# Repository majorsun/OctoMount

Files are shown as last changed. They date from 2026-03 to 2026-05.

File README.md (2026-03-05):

# OctoMount

A 3D-printable mounting enclosure that attaches a **Raspberry Pi 4B** with **MPI4008 4" LCD touchscreen** to an **Ender 3 Pro** 3D printer frame.

Designed for use with [OctoPrint](https://octoprint.org/) — giving you a compact, integrated control panel mounted directly on your printer.

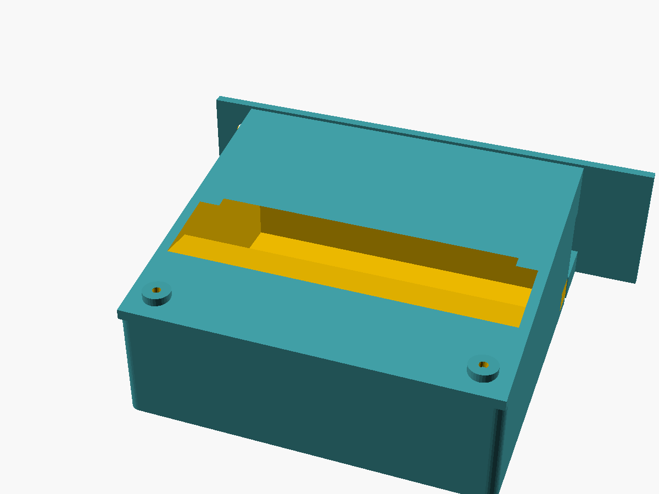
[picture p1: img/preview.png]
CAD Preview


> Preview auto-generated from `cad/assembly.scad` via `scripts/render_preview.sh`.
> Re-run the script after any CAD change to keep this image current.

---

## Hardware

| Component | Model | Notes |
|---|---|---|
| Single Board Computer | Raspberry Pi 4B | 2GB/4GB/8GB variants |
| Display | MPI4008 (LCDwiki 4" HDMI Display-C) | 800×480 IPS, resistive touch |
| Printer | Creality Ender 3 Pro | 4040 aluminum extrusion frame |

### MPI4008 Display Specs

- **Size:** 4.0 inch IPS
- **Resolution:** 800 × 480
- **Touch:** 4-wire resistive
- **Interface:** HDMI (video) + 13×2 GPIO header (power + touch)
- **Module dimensions:** 143 × 134 × 51 mm (with RPi stacked)

### Raspberry Pi 4B Specs

- **Dimensions:** 85 × 56 × 17 mm
- **Ports used:** HDMI micro (to LCD), USB-A (printer connection), USB-C (power in)

---

## Design Overview

OctoMount is a **2-piece design** — Base and Cover — that replaces the Ender 3 Pro control box front panel:

- **Base** — single printed part that serves as both the mounting bracket and the enclosure body. It bolts to the 4040 control-box beam using the existing two M5 diagonal screw holes, covers the stock front panel, and houses the RPi 4B, LM2596 buck converter, and full-size SD slot.
- **Cover** — angled lid that screws onto the Base. The back wall is at the full 48 mm height limit; the front wall is as short as the flat RPi stack allows, maximising the LCD tilt toward the operator. Attaches with 4× M3 screws.

### Mounting Strategy

The Base plate bolts directly to the end face of the Ender 3 Pro 4040 control-box beam using **2× M5 flat-head screws** in the existing diagonal hole pattern (top-left at 10,10 mm; bottom-right at 30,30 mm). Longer M5 screws pass through the Base plate and original plastic panel into the beam — no new holes required.

### Port Routing

| Port | Location | Purpose |
|---|---|---|
| Full-size SD slot | Left wall of Base | Ender 3 Pro microSD extension (print file access) |
| USB-A | Back wall of Base | Cable to Ender 3 Pro mainboard USB (routed through control box) |
| USB-C power | Right-bottom corner of Base | 5V from LM2596 buck converter, entering via 4040 T-slot channel |
| Micro HDMI | Internal | RPi → MPI4008 LCD (inside enclosure) |

---

## Project Goals

- [x] Design a 2-piece 3D-printable enclosure for RPi 4B + MPI4008 LCD + LM2596 buck converter
- [x] Mount to the Ender 3 Pro 4040 beam end face via existing M5 screw holes
- [ ] Power from Ender 3 Pro 24V PSU via LM2596 buck converter (→ 5V USB-C for RPi)
- [ ] Expose full-size SD slot on left wall (extended from Ender 3 Pro microSD)
- [ ] Route USB-A cable from Ender 3 Pro mainboard through back wall to RPi
- [ ] LCD tilt maximised toward operator (back wall at 48 mm, front wall at minimum height above flat RPi stack)
- [ ] Integrated fan ventilation with permanent dust filter mesh

---

## Deliverables

| File | Description | Status |
|---|---|---|
| `PARTS.md` | Full bill of materials — parts to buy + 3D printed parts list | ✅ Updated |
| `REQUIREMENTS.md` | Full design requirements | ✅ Updated |
| `stl/` | 3D print files (2 parts: Base + Cover) | 🔄 Pending CAD redesign |
| `docs/ASSEMBLY.md` | Enclosure diagram + step-by-step assembly instructions | 🔄 Pending |
| `img/wiring_diagram.png` | Wiring diagram (PSU → buck converter → RPi) | 🔄 Pending |
| `img/preview.png` | Auto-rendered CAD preview (regenerated by `scripts/render_preview.sh`) | ✅ Active |
| `img/renders/` | Final high-quality CAD renders | 🔄 Pending CAD |

---

## 3D Printed Parts

| Part | Description |
|---|---|
| Base | Mounting plate + arm shelf + enclosure walls + RPi bosses + SD slot + buck converter mount |
| Cover | Angled lid (45° front-top face) with LCD window cutout; attaches with 4× M3 screws |

---

## Repository Structure

```
OctoMount/
├── README.md
├── REQUIREMENTS.md        # Full design requirements
├── STATUS.md              # Project phase tracker
├── PARTS.md               # Bill of materials
├── cad/                   # OpenSCAD source files
├── stl/                   # Export-ready STL files for printing
│   ├── Base.stl
│   └── Cover.stl
├── docs/
│   └── ASSEMBLY.md        # Assembly instructions
├── scripts/
│   └── render_preview.sh  # Regenerate img/preview.png from CAD
└── img/                   # Renders, wiring diagram, photos
    └── preview.png        # Auto-rendered CAD preview
```

---

## Software

- [OctoPrint](https://octoprint.org/) — web-based 3D printer control
- [OctoPi](https://github.com/guysoft/OctoPi) — Raspberry Pi OS image with OctoPrint pre-installed
- [LCD driver (goodtft)](https://github.com/goodtft/LCD-show) — MPI4008 display driver (`sudo ./MPI4008-show`)

---

## Printing Notes

- Material: PETG recommended (heat resistance near printer)
- Layer height: 0.2 mm
- Infill: 30%+
- Supports: Minimal (design oriented to minimise overhangs)

---

## License

[MIT](LICENSE) — free to use, modify, and share.

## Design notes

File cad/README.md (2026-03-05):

# OctoMount — CAD Files

All source models are written in **OpenSCAD** (parametric, text-based CAD).

## Install OpenSCAD

Download the latest stable release from <https://openscad.org/downloads.html>
(Windows / macOS / Linux — free, open source)

## File overview

| File | Description | Render to get… |
|---|---|---|
| `params.scad` | All dimensions + derived values + shared modules | *(not a standalone part)* |
| `assembly.scad` | All parts positioned together | Full assembly preview |
| `p1_enclosure.scad` | Main body shell | `OctoMount_enclosure.stl` |
| `p2_bracket.scad` | 2020 extrusion clamp + tilted arm | `OctoMount_bracket.stl` |
| `p3_bezel.scad` | LCD front bezel + stylus clip | `OctoMount_bezel.stl` |
| `p4_rear_panel.scad` | Rear panel with hex vent cutouts | `OctoMount_rear_panel.stl` |
| `p5_buck_tray.scad` | Buck converter retention tray | `OctoMount_buck_tray.stl` |

## How to render a part

1. Open the `.scad` file in OpenSCAD
2. Press **F5** for a fast preview, or **F6** for a full render
3. Check the **Console** tab at the bottom — no errors means the geometry is valid
4. Export: **File → Export → Export as STL…** → save to `../stl/`

## How to render the assembly

1. Open `assembly.scad`
2. Press **F5** (preview) — colour-coded parts help distinguish components
3. Set `EXPLODE = 1;` at the top of the file for an exploded view, then press F5 again

## Iterating on dimensions

All dimensions live in **`params.scad`**.
- Items marked `// TBD` must be confirmed against the physical hardware before printing
- Edit the relevant parameter value, save, and press F5 in OpenSCAD to see the change
- No other files need changing for pure dimension tweaks

## Which file to open for each change

| Change type | File to edit |
|---|---|
| Hardware dimensions, clearances | `params.scad` |
| New openings, port positions, cavity shape | `p1_enclosure.scad` |
| Bracket tilt angle, clamp depth, arm length | `p2_bracket.scad` |
| Bezel border width, stylus clip profile | `p3_bezel.scad` |
| Vent pattern size/density, voltmeter window | `p4_rear_panel.scad` |
| Buck tray inner dimensions, wire holes | `p5_buck_tray.scad` |

## Print settings (recommended)

- Material: **PETG** (heat resistant near printer, good layer adhesion)
- Layer height: 0.2 mm
- Walls: 3 perimeters
- Infill: 30 % gyroid
- Supports: only on bracket arm overhang if TILT > 45°

## TBD items (measure before final print)

See `params.scad` — every line marked `// TBD` needs physical measurement:

- LCD PCB outer dimensions (`LCD_PCB_X`, `LCD_PCB_Z`, `LCD_T`)
- RPi 4B total thickness with heatsinks (`RPI_T`)
- Fan size and thickness (`FAN_SIZE`, `FAN_T`)
- Buck converter PCB dimensions (`BUCK_L`, `BUCK_H`, `BUCK_W`)
- All port centre positions on RPi (`RPI_ETH_Z`, `RPI_USBC_Z`, etc.)
- Stylus diameter (`STYLUS_D`)
- SD extension slot opening size (`SD_SLOT_W`, `SD_SLOT_H`)

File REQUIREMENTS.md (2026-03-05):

# Design Requirements

**Last Updated:** 2026-03-04 (rev 2)
**Design:** 2-piece enclosure (Base + Cover) — see STATUS.md for design pivot history

---

## REQ-001 — Hardware Compatibility

| ID | Requirement | Priority |
|---|---|---|
| REQ-001.1 | Base must house Raspberry Pi 4B (85 × 56 × 17 mm) with clearance | MUST |
| REQ-001.2 | Cover must provide an angled LCD window for the MPI4008 display (active area ~87 × 52 mm) | MUST |
| REQ-001.3 | Base must bolt to the Ender 3 Pro 4040 control-box beam end face via 2× M5 flat-head screws | MUST |
| REQ-001.4 | USB-C power port on RPi must receive 5V from the internal LM2596 buck converter via a USB-C pigtail routed through the right-bottom corner | MUST |
| REQ-001.5 | A USB-A cable must exit through the back wall of the base to connect the RPi to the Ender 3 Pro mainboard USB port (routed internally through the control box) | MUST |
| REQ-001.6 | RPi microSD slot is not required to be accessible from outside (OctoPi OS is pre-flashed) | INFO |
| REQ-001.7 | Micro HDMI port on RPi must be routed to the LCD internally | MUST |
| REQ-001.8 | MPI4008 GPIO 13×2 header connection to RPi must be accommodated | MUST |
| REQ-001.9 | Enclosure must include a full-size SD card slot on the left wall, connected via microSD male → SD female extension cable (AliExpress item 2255801037535913) to the Ender 3 Pro control box microSD slot | MUST |
| REQ-001.10 | SD extension cable must reach from the Ender 3 Pro mainboard to the left-wall SD slot without tension — verify cable length before ordering | MUST |
| REQ-001.11 | MPI4008 backlight button access is optional | NICE-TO-HAVE |
| REQ-001.12 | MPI4008 3.5mm audio jack access is not required | OUT-OF-SCOPE |

---

## REQ-002 — Structural & Mounting

| ID | Requirement | Priority |
|---|---|---|
| REQ-002.1 | Base plate must bolt to the Ender 3 Pro 4040 control-box front beam end face using 2× M5 flat-head screws in the existing diagonal hole pattern (10,10) and (30,30) — 20 mm apart in X and Z | MUST |
| REQ-002.2 | The base plate covers the stock Ender 3 Pro control box front panel entirely | MUST |
| REQ-002.3 | Assembly must withstand vibration during printing without loosening | MUST |
| REQ-002.4 | No 2020 T-slot nuts or 2020 clamp hardware required | MUST |
| REQ-002.5 | Total enclosure height (Z, including all walls) must not exceed **48 mm** — hard clearance limit from the Ender 3 Pro bed assembly | MUST |
| REQ-002.6 | RPi 4B must be mounted flat (85 × 56 mm footprint in XY, PCB+heatsinks ~17–25 mm in Z) — standing on-edge is ruled out by the 48 mm height limit | MUST |
| REQ-002.7 | LCD tilt must be **maximised toward the operator**: back wall at the full 48 mm, front wall at the minimum height dictated by the flat RPi stack + clearance. Do not target a fixed angle — derive it from the geometry | MUST |
| REQ-002.8 | Side silhouette: right-trapezoid — back wall tall (48 mm), front wall short (minimum), angled top face spanning between them holding the LCD | MUST |
| REQ-002.9 | Assembly must support the combined weight of RPi 4B + LCD without flex | MUST |
| REQ-002.10 | Assembly must not protrude into the path of the printer bed (Y-axis travel) | MUST |
| REQ-002.11 | Assembly must not obstruct the X-axis gantry wheels or carriage movement | MUST |
| REQ-002.12 | Full-size SD card slot must be on the left wall and allow one-handed card insertion/removal | MUST |
| REQ-002.13 | Cover must attach to Base with M3 screws (no glue) and be removable for service | MUST |

---

## REQ-003 — Power

| ID | Requirement | Priority |
|---|---|---|
| REQ-003.1 | Assembly must draw power from the Ender 3 Pro PSU (24V DC) — no separate wall adapter | MUST |
| REQ-003.2 | Buck converter model: LM2596-based adjustable step-down (Temu goods_id 601099525293943) | MUST |
| REQ-003.3 | Buck converter must be set to output 5V DC for RPi 4B | MUST |
| REQ-003.4 | Buck converter output must supply at least 3A continuous | MUST |
| REQ-003.5 | Buck converter must be mounted inside the base body with adhesive thermal pad/heatsink (~14 × 14 mm aluminum) | MUST |
| REQ-003.6 | 5V output must connect to RPi via USB-C pigtail (not GPIO pins) | MUST |
| REQ-003.7 | USB-C power cable must enter the enclosure through the right-bottom corner, routed through the 4040 beam T-slot channel | MUST |
| REQ-003.8 | 24V tap must be taken from the PSU terminals or a safe splice point | MUST |
| REQ-003.9 | Wiring must include a fuse or polyfuse on the 24V input line | SHOULD |

---

## REQ-004 — Thermal Management

| ID | Requirement | Priority |
|---|---|---|
| REQ-004.1 | Enclosure must provide clearance for the integrated fan mounted between the LCD and RPi 4B modules | MUST |
| REQ-004.2 | Enclosure must have ventilation openings aligned with the fan's intake and exhaust paths | MUST |
| REQ-004.3 | Ventilation area must be sufficient to not back-pressure the integrated fan (open area ≥ fan blade swept area) | MUST |
| REQ-004.4 | Heatsinks on RPi 4B CPU/RAM must have clearance inside the enclosure | MUST |
| REQ-004.5 | Enclosure must not trap heat near the Ender 3 Pro heated bed or hotend | MUST |
| REQ-004.6 | Ventilation openings should incorporate a dust filter screen | SHOULD |

---

## REQ-005 — Printability

| ID | Requirement | Priority |
|---|---|---|
| REQ-005.1 | All parts must be printable on an Ender 3 Pro (235 × 235 × 250 mm build volume) | MUST |
| REQ-005.2 | Minimum wall thickness: 2 mm (3 mm preferred for structural walls) | MUST |
| REQ-005.3 | Design consists of exactly 2 printed parts: Base and Cover | MUST |
| REQ-005.4 | Parts should minimise required supports | SHOULD |
| REQ-005.5 | Recommended print material: PETG (heat resistant, durable) | SHOULD |

---

## REQ-006 — Assembly & Serviceability

| ID | Requirement | Priority |
|---|---|---|
| REQ-006.1 | RPi must be removable with only a screwdriver | SHOULD |
| REQ-006.2 | Cover must be removable independently for LCD or RPi service | MUST |
| REQ-006.3 | Assembly must be completable by a maker with basic tools | MUST |
| REQ-006.4 | Provide assembly documentation with the design files | SHOULD |

---

## REQ-007 — Aesthetics

| ID | Requirement | Priority |
|---|---|---|
| REQ-007.1 | Design should be clean and intentional, not purely functional | NICE-TO-HAVE |
| REQ-007.2 | Branding / logo emboss on exterior is optional | NICE-TO-HAVE |
| REQ-007.3 | Cable routing should be hidden where possible | SHOULD |

---

## Reference Dimensions

### Raspberry Pi 4B
- PCB: 85 × 56 mm
- Height with heatsinks: ~25 mm
- Mounting holes: 3.5 mm dia., 58 × 49 mm pattern (M2.5 standoffs)

### MPI4008 LCD Module
- Overall: 143 × 134 × 51 mm (including RPi when stacked)
- Active area: ~87 × 52 mm (4.0" diagonal)
- GPIO header: 13×2, standard 2.54 mm pitch
- Integrated fan: in the gap between LCD board and RPi — **measure fan size and orientation before CAD** (likely 30×30 mm or 40×40 mm)

### Ender 3 Pro 4040 Control-Box Beam
- Cross-section: 40 × 40 mm
- Front end face: 2× M5 threaded holes at (10,10) and (30,30) mm from corner
- Hole spacing: 20 mm in X, 20 mm in Z (diagonal 28.3 mm)
- Existing screws hold the stock control box front panel — replace with longer M5 flat-heads that pass through the OctoMount base plate + original plastic panel → into beam

### SD Card Extension (AliExpress item 2255801037535913)
- Type: microSD male plug → full-size SD card female socket, panel-mount
- Socket end: flush-mounted on left wall of base
- Lengths typically available: 15 cm / 48 cm — **measure routing path before ordering**
- Full-size SD socket panel cutout: ~32 × 3 mm slot — **verify against physical unit**

### Buck Converter (LM2596 + voltmeter, Temu goods_id 601099525293943)
- Input: 4–40V DC (Ender 3 Pro 24V PSU)
- Output: 1.25–37V DC adjustable — set to 5V for RPi 4B
- Max current: 3A
- PCB dimensions: ~48 × 23 × 14 mm — **measure physical unit before CAD**
- Heatsink: adhesive ~14 × 14 mm aluminum pad on LM2596 IC

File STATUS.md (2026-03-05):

# Project Status

**Last Updated:** 2026-03-04
**Current Phase:** CAD Design (2-piece redesign)

---

## Design Pivot — 2026-03-04

The original 5-piece design (enclosure body + bezel + bracket arm + rear panel + buck tray) has been replaced with a **2-piece design**:

- **Base** — single printed part: mounting plate + arm shelf + enclosure walls + RPi standoff bosses + left-wall SD slot + internal buck converter mount
- **Cover** — angled lid with 45° front-top face; houses the LCD window; attaches to Base with 4× M3 screws

Key changes from original design:
- Mounting: M5 flat-head screws into 4040 beam end face (replaces 2020 T-slot clamp)
- LCD tilt: maximised — back wall at 48 mm (hard limit), front wall at minimum height above flat RPi stack; angle derived from geometry, not fixed at 45°
- USB-A: exits back wall to Ender 3 Pro mainboard (not top face)
- USB-C: enters right-bottom corner via 4040 T-slot channel
- Buck converter: inside base body with adhesive heatsink (no separate tray part)
- Removed: stylus clip, separate bezel (P3), rear panel (P4), buck tray (P5)

Old 5-piece OpenSCAD files remain in `cad/` as reference but are superseded.

---

## Phase Overview

| Phase | Name | Status |
|---|---|---|
| 1 | Planning & Requirements | Complete |
| 2 | CAD Design | In Progress |
| 3 | Prototype Print | Not Started |
| 4 | Fit & Function Testing | Not Started |
| 5 | Revision & Polish | Not Started |
| 6 | Documentation & Release | Not Started |

---

## Phase 1 — Planning & Requirements

- [x] Define hardware components (RPi 4B + MPI4008 + Ender 3 Pro)
- [x] Document design requirements (see REQUIREMENTS.md)
- [x] Gather hardware reference dimensions
- [x] Define bill of materials (see PARTS.md)
- [x] Select CAD tool → **OpenSCAD** (parametric, Claude-editable .scad files)
- [x] Confirm mounting location → 4040 control-box beam end face (2× M5 diagonal screws)
- [x] Confirm design architecture → 2-piece: Base + Cover
- [ ] Measure integrated fan size and orientation (MPI4008 kit)
- [ ] Measure buck converter PCB dimensions (physical unit)
- [ ] Confirm SD extension cable length against routing path

---

## Phase 2 — CAD Design

### Superseded (5-piece) — archived in cad/legacy/
- [x] p1_enclosure.scad, p2_bracket.scad, p3_bezel.scad, p4_rear_panel.scad, p5_buck_tray.scad

### 2-Piece Redesign (active)
- [x] params.scad — rewritten: flat RPi orientation, derived BASE_OUTER_Z=32mm, COVER_BACK_Z=16mm, LCD tilt ~8° from horizontal
- [x] base.scad — mounting plate + arm shelf + open-top tray + RPi standoff bosses + M3 cover bosses + USB-A/Ethernet back wall + USB-C right-bottom + SD left wall + M5 plate holes
- [x] cover.scad — hull()-based trapezoid shell + LCD window + PCB recess + M3 corner holes
- [x] assembly.scad — positions Base + Cover; EXPLODE=1 option
- [ ] Confirm all TBD dimensions against physical hardware before export
- [ ] Iterate port positions from first prototype print
- [ ] Export STLs for prototype print

---

## Phase 3 — Prototype Print

- [ ] Print Base
- [ ] Print Cover
- [ ] Dry-fit assembly (no hardware)

---

## Phase 4 — Fit & Function Testing

- [ ] Test RPi 4B seating and standoff alignment
- [ ] Test LCD fit and cover clearance
- [ ] Test M5 mounting to 4040 beam end face
- [ ] Test port access (SD left wall, USB-A back wall, USB-C right-bottom corner)
- [ ] Test USB cable routing from Ender 3 Pro mainboard through back wall
- [ ] Test SD extension cable reach and routing
- [ ] Test fan airflow through ventilation openings
- [ ] Test thermal performance under OctoPrint load
- [ ] Test vibration resistance during a print job
- [ ] Verify assembly clears printer bed Y-axis travel and X-axis gantry wheels

---

## Phase 5 — Revision & Polish

- [ ] Address any fit issues from Phase 4
- [ ] Final surface / aesthetic refinements
- [ ] Finalize print settings recommendation

---

## Phase 6 — Documentation & Release

- [ ] Finalize assembly guide (docs/ASSEMBLY.md) with photos and wiring diagram
- [ ] Add renders to img/
- [ ] Publish STL files to stl/
- [ ] Write OctoPrint + MPI4008 software setup guide
- [ ] Update PARTS.md with final confirmed part specs
- [ ] Tag v1.0 release on GitHub

---

## Issues & Blockers

| # | Description | Status |
|---|---|---|
| 1 | Fan size and orientation (MPI4008 kit) not yet measured — needed before enclosure depth is final | Open |
| 2 | Buck converter PCB dimensions not yet confirmed — needed before base cavity sizing | Open |
| 3 | SD extension cable length not yet verified against routing path | Open |
| 4 | M5 screw length depends on physical control box panel thickness — measure before ordering | Open |

---

## Notes

- MPI4008 stacks directly onto RPi GPIO — combined stack height drives enclosure internal Z.
- Integrated fan sits in the gap between LCD board and RPi — measure size and orientation before CAD.
- Power: 24V PSU → LM2596 buck converter (inside Base, adhesive heatsink) → 5V USB-C → RPi 4B.
- PETG strongly recommended over PLA due to heat from the printer environment.

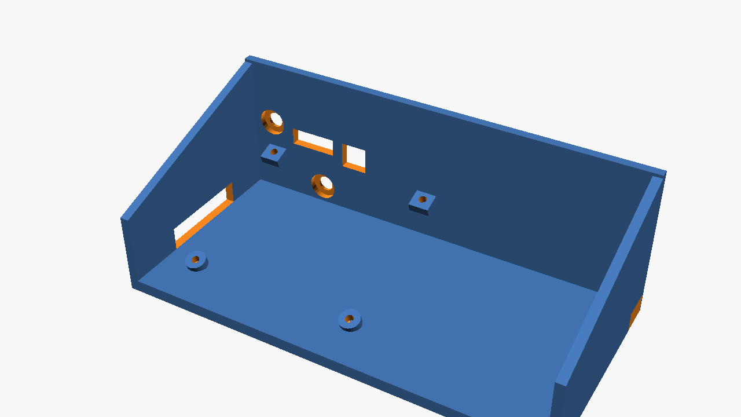
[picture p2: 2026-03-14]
preview_base.png

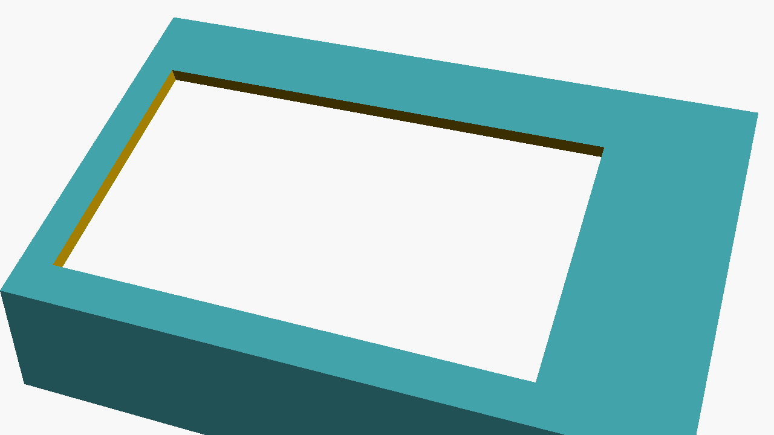
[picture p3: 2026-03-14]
preview_cover.png

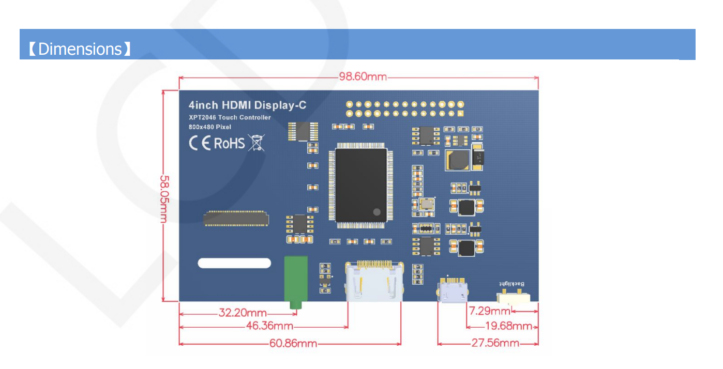
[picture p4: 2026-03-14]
reference/LCD diagram.png

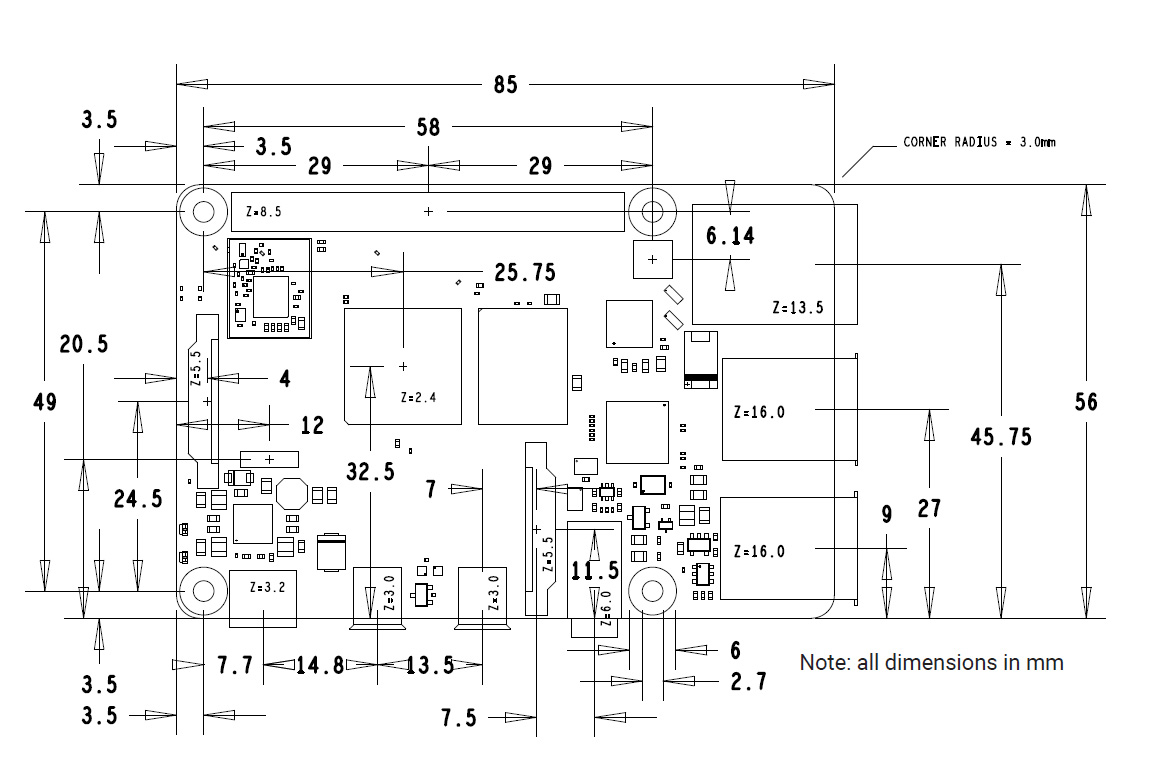
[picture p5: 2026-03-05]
reference/Pi-4-Physical-size.jpg

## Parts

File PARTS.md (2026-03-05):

# Parts List / Bill of Materials

**Project:** OctoMount — RPi 4B + MPI4008 LCD enclosure for Ender 3 Pro
**Last Updated:** 2026-03-04
**Design:** 2-piece (Base + Cover)

Legend: ✅ On hand / ordered &nbsp;|&nbsp; 🛒 Needs to be purchased &nbsp;|&nbsp; 🖨️ 3D printed

---

## 1. Core Electronics

| # | Item | Spec | Source | Status | Notes |
|---|---|---|---|---|---|
| 1 | Raspberry Pi 4B | 2GB / 4GB / 8GB | — | ✅ | Running OctoPi |
| 2 | MPI4008 LCD Kit | 4" HDMI, 800×480, resistive touch, w/ integrated fan | LCDwiki / Miuzei | ✅ | Includes GPIO stacking header and fan |
| 3 | Buck converter | LM2596 adjustable step-down w/ LED voltmeter | Temu (goods_id 601099525293943) | ✅ | Set output to 5V |
| 4 | SD card extension | microSD male → full-size SD female, panel-mount | AliExpress (item 2255801037535913) | ✅ | Verify cable length before routing |
| 5 | LM2596 adhesive heatsink | ~14 × 14 mm aluminum thermal pad, self-adhesive | AliExpress / Amazon | 🛒 | Sticks to LM2596 IC on buck converter PCB |

---

## 2. Cables & Connectors

| # | Item | Spec | Source | Status | Notes |
|---|---|---|---|---|---|
| 6 | USB-A extension / short cable | USB-A male → USB-A female or short patch, ~20–30 cm | Amazon / local | 🛒 | Routes from Ender 3 Pro control box mainboard USB → RPi USB-A through back wall |
| 7 | USB-C pigtail / breakout | USB-C male plug with bare wire ends, 5V/3A rated | Amazon / AliExpress | 🛒 | Buck converter 5V output → RPi USB-C power in |
| 8 | 24V tap wire | 22 AWG stranded, red + black, ~50 cm | Local electronics | 🛒 | PSU terminal → buck converter input |
| 9 | Wire ferrules or spade terminals | For PSU terminal connections | Local electronics | 🛒 | Crimped connection to PSU screw terminals |

---

## 3. Protection & Power Safety

| # | Item | Spec | Source | Status | Notes |
|---|---|---|---|---|---|
| 10 | Polyfuse (resettable fuse) | 24V, 1A hold / 2A trip, inline | DigiKey / Mouser | 🛒 | On 24V input line before buck converter |
| 11 | Heat shrink tubing | Assorted 2–6 mm | Local | 🛒 | Insulate all bare wire splices |

---

## 4. Fasteners & Hardware

| # | Item | Spec | Qty | Source | Status | Notes |
|---|---|---|---|---|---|---|
| 12 | M5 flat-head screws | M5 × 12 mm countersunk (measure actual panel thickness before ordering) | 2 | Local / Amazon | 🛒 | Attach base plate to 4040 beam end face, replacing original control-box screws |
| 13 | M2.5 × 8 mm screws | Socket head or countersunk | 4 | Local / Amazon | 🛒 | RPi 4B PCB standoff mounting |
| 14 | M2.5 brass standoffs (M-F) | M2.5, ~5 mm height | 4 | Amazon / AliExpress | 🛒 | Raise RPi PCB off base floor |
| 15 | M3 screws for cover | M3 × 8 mm socket head | 4 | Local / Amazon | 🛒 | Attach Cover to Base |
| 16 | M3 heat-set inserts (optional) | M3, standard press-fit | 4 | Amazon / AliExpress | 🛒 | Optional: for M3 cover attachment into Base bosses |

---

## 5. Filtration & Finishing

| # | Item | Spec | Source | Status | Notes |
|---|---|---|---|---|---|
| 17 | Dust filter mesh | Fine nylon or foam sheet, ~100 × 100 mm | Amazon / AliExpress | 🛒 | Cut to fit ventilation openings; permanently glued in |
| 18 | Micro SD card | 16GB+ Class 10 / A1 | Amazon | 🛒 | RPi OS (OctoPi image) |

---

## 6. 3D Printed Parts

> STL files will be published in `/stl` once CAD redesign is complete.

| # | Part | Material | Est. Print Time | Notes |
|---|---|---|---|---|
| P1 | Base | PETG | TBD | Mounting plate + arm shelf + enclosure walls + RPi bosses + SD slot + buck cavity |
| P2 | Cover | PETG | TBD | Angled lid with 45° front-top face; LCD window cutout; attaches to Base with 4× M3 screws |

---

## Summary

| Category | Items | Estimated Cost |
|---|---|---|
| Core electronics | 5 items | Mostly on hand; ~$3–5 for heatsink |
| Cables & connectors | 4 items | ~$10–15 |
| Protection & safety | 2 items | ~$5 |
| Fasteners | 5 items | ~$8–12 |
| Filtration & finishing | 2 items | ~$3–5 |
| 3D printed parts | 2 parts | Filament only (~$2–3) |

> Cost estimates are approximate. Verify prices at time of purchase.

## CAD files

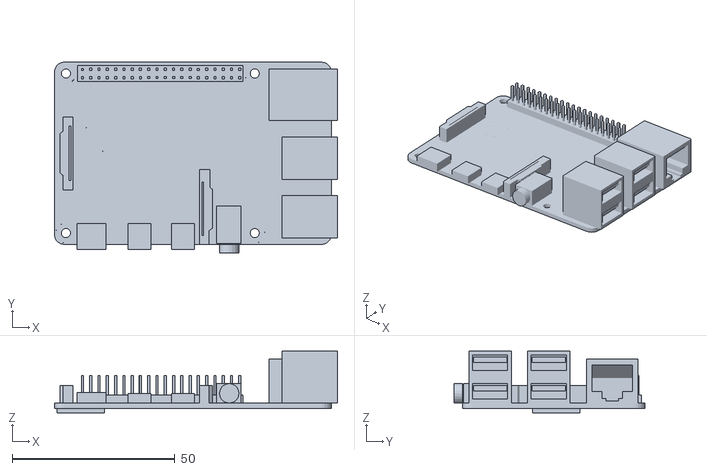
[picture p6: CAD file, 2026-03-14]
reference/Raspberry_Pi_4_B_3D_Model.stl
86.9 x 58.6 x 19.0

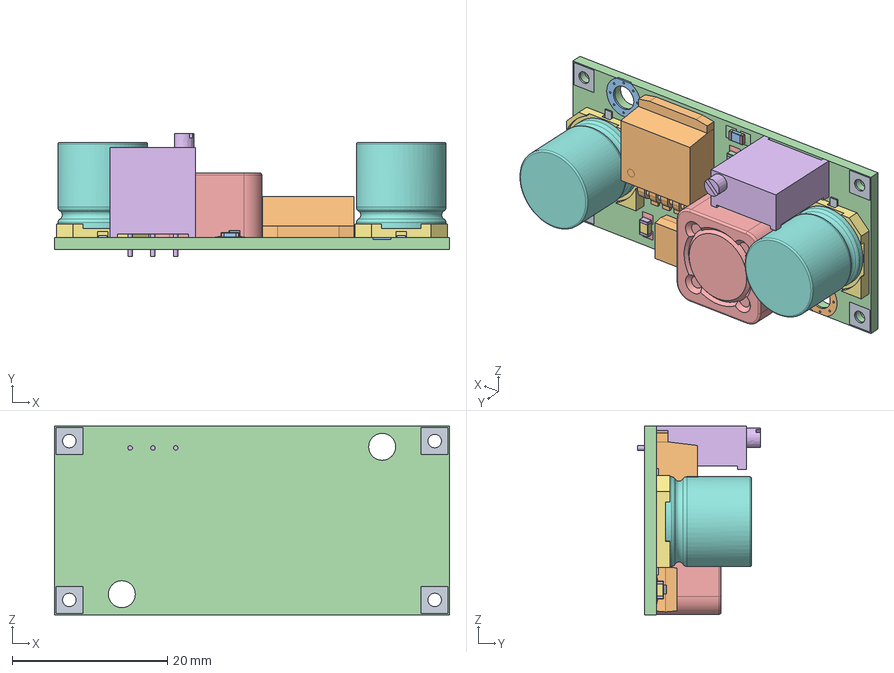
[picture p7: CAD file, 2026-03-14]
reference/6811d70143b4d50b11a59159.step
50.9 x 15.8 x 24.3 mm

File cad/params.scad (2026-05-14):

// ============================================================
// OctoMount — params.scad  (2-piece redesign)
// All hardware dimensions, design parameters, derived values,
// and shared utility modules.
//
// RPi 4B orientation: FLAT
//   X = RPi short axis (56 mm) — left/right in enclosure
//   Y = RPi long  axis (85 mm) — front/back in enclosure
//   Z = RPi stack height       — up/down, total outer height ≤ 52 mm
//
//   USB-A / Ethernet short edge → BACK  wall (+Y face)
//   USB-C / HDMI    short edge → FRONT wall (-Y face, internal pigtails)
//   GPIO long edge             → LEFT  wall (-X face)
//
// Items marked "TBD" must be measured before a final print.
// All dimensions in millimetres.
// ============================================================

// ── Fasteners ────────────────────────────────────────────────
M3_CLEAR       = 3.4;    // M3 clearance hole diameter
M3_TAP         = 2.5;    // M3 tap diameter (PETG self-tap)
M3_CS_D        = 6.0;    // M3 flat-head countersink outer diameter
M3_CS_H        = 2.0;    // M3 countersink depth
M3_BOSS_R      = 4.0;    // M3 boss outer radius
M3_BOSS_DEPTH  = 6.0;    // M3 blind tapped-hole depth

M25_CLEAR      = 2.7;    // M2.5 clearance hole (RPi mounting)
M25_BOSS_R     = 3.5;    // M2.5 boss outer radius
M25_BOSS_DEPTH = 3.0;    // M2.5 blind hole depth (≤ STOFF_H)

M5_CLEAR  = 5.5;   // M5 clearance hole (4040 beam mount)
M5_CS_D   = 9.5;   // M5 flat-head countersink OD (matches 4040 spec)
M5_CS_H   = 2.0;   // M5 countersink depth

// ── Shell ─────────────────────────────────────────────────────
WALL     = 3.0;   // nominal wall — clearances, hinge boss, cover geometry
WALL_S   = 2.0;   // structural side + back wall thickness (thinner than hinge boss)
CLR      = 1.0;   // per-side assembly clearance
CORNER_R = 3.0;   // outer corner rounding radius
$fa = 3;  $fs = 0.5;

// ── Raspberry Pi 4B (rotated 90° CW in enclosure — long axis along X) ──────
// Reference: Pi-4-Physical-size.jpg
//   USB-A Z=16.0mm, ETH Z=13.5mm, USB-C Z=6.0mm, microHDMI Z=3.0mm (all from PCB top)
// RPi long edge (85mm) aligned with LCD PCB long edge (98.6mm), both in enclosure X.
// 90° CW rotation viewed from LCD front face.
// GPIO flex cable required (direct GPIO plug-in not valid in this orientation).
// Ports after rotation:
//   USB-A / ETH  short edge → LEFT  wall (−X face)           — TBD verify
//   USB-C / HDMI short edge → RIGHT wall (+X face)           — TBD verify
//   GPIO long edge          → toward cover front (−Y face)   — internal, no wall exit
RPI_X    = 85.0;   // PCB long  axis → enclosure X (rotated 90° CW)
RPI_Y    = 56.0;   // PCB short axis → enclosure Y
RPI_T    = 18.0;   // GPIO-face → heatsink tip height — TBD (heatsink height not yet measured)
RPI_PCB_T =  1.2;  // bare PCB thickness (confirmed)

// Mounting holes (rotated 90° CW with PCB — DX↔DY swapped; OX, OY unchanged):
RPI_HOLE_DX  = 58.0;   // hole-to-hole in X (physical long-axis spacing, now in X)
RPI_HOLE_DY  = 49.0;   // hole-to-hole in Y (physical short-axis spacing, now in Y)
RPI_HOLE_OX  =  3.5;   // offset from RPi −X edge to nearest hole column
RPI_HOLE_OY  =  3.5;   // offset from RPi −Y edge to nearest hole row

// Port positions — all TBD: measure on physical RPi in final orientation.
// USB-A / ETH ports exit through LEFT wall (−X face).
//   _Y = distance of port centre along the RPi −X edge from the RPi −Y (front) edge.
//   _W = opening width in enclosure Y;  _H = opening height in Z;  _Z = bottom Z above base floor.
PORT_USBA_Y   = 28.0;   // USB-A 4-port stack centre: Y from RPi front edge  — TBD
PORT_USBA_W   = 32.0;   // USB-A combined opening width  (Y)                  — TBD
PORT_USBA_H   = 16.0;   // USB-A combined opening height (Z)                  — TBD
PORT_USBA_Z   =  9.0;   // USB-A opening bottom Z above base floor             — TBD
PORT_ETH_Y    =  9.0;   // Ethernet centre: Y from RPi front edge              — TBD
PORT_ETH_W    = 20.0;   // Ethernet opening width  (Y)                         — TBD
PORT_ETH_H    = 16.0;   // Ethernet opening height (Z)                         — TBD
PORT_ETH_Z    =  9.0;   // Ethernet opening bottom Z above base floor          — TBD
// USB-C / HDMI ports exit through RIGHT wall (+X face).
PORT_USBC_Y   = 36.0;   // USB-C centre: Y from RPi front edge  — TBD
PORT_USBC_W   = 11.0;   // USB-C opening width  (Y)
PORT_USBC_H   =  7.0;   // USB-C opening height (Z)

// ── Right-wall ventilation grill (round holes) ────────────────
// Round holes through the 1 mm right wall, over the buck converter zone.
// Hole centres are kept ≥ VENT_HOLE_R from every zone boundary so
// no hole overlaps the floor, wall top, or front/back wall edges.
VENT_Y0         = 15.0;   // hole centre Y min (world Y) — 15 mm clear of front wall
VENT_Y1         = 64.0;   // hole centre Y max (world Y) — 9 mm clear of back wall
VENT_Z0         =  1.0;   // zone bottom (world Z); centres start at VENT_Z0+VENT_HOLE_R
VENT_Z1         = 33.0;   // zone top   (world Z); centres end   at VENT_Z1-VENT_HOLE_R
VENT_HOLE_R     =  2.5;   // hole radius (5 mm diameter)
VENT_HOLE_PITCH =  6.0;   // centre-to-centre spacing in Y and Z (2 mm land between holes)

// ── MPI4008 4″ LCD ────────────────────────────────────────────
// The LCD plugs directly onto the RPi 40-pin GPIO header — their
// relative XY position is mechanically fixed and must be measured
// as a coupled assembly.  Offsets below are from RPi PCB centre.
LCD_PCB_X  = 100;    // LCD PCB width  (along enclosure X) — from manual diagram
LCD_PCB_SL = 60;   // LCD PCB depth along slope (enclosure Y) — from manual diagram
LCD_T      =  5.8;    // LCD module thickness (perp. to face) — measured
LCD_ACT_X  = 100;    // active area width  (confirmed)
LCD_ACT_SL = 60;    // active area height along slope (confirmed)
// GPIO flex cable connects RPi (rotated 90° CW) to LCD.
// LCD orientation: chip side faces RPi (screen faces outward through cover window).
// LCD coupling offsets must be re-derived from physical flex-cable assembly.  TBD.
LCD_OFS_X  = (LCD_PCB_X - RPI_X) / 2;  // = 6.8 mm — left edge of LCD PCB aligned with left edge of RPi PCB
LCD_OFS_Y  =  0.0;    // TBD — re-measure with RPi in rotated orientation

// ── LCD panel layer (the front display glass, slightly smaller than PCB) ─
// The module has two layers back-to-back:
//   back  layer (faces RPi): the PCB board  (LCD_PCB_X × LCD_PCB_SL)
//   front layer (faces out): the LCD panel  (slightly smaller, fits in cover window)
// Setbacks = how much each panel edge is inset from the corresponding PCB edge.
// All marked TBD — measure the physical module before printing.
LCD_PANEL_T    =  2.5;   // panel/glass thickness (perp. to face)   — TBD measure
LCD_SB_LEFT    =  0;   // setback: PCB -X edge → panel -X edge     — TBD measure
LCD_SB_RIGHT   =  0;   // setback: PCB +X edge → panel +X edge     — TBD measure
LCD_SB_FRONT   =  0;   // setback: PCB low-slope edge → panel edge  — TBD measure
LCD_SB_BACK    =  0;   // setback: PCB high-slope edge → panel edge — TBD measure

// Derived panel dimensions and centre offset from PCB centre
LCD_PANEL_X    = LCD_PCB_X  - LCD_SB_LEFT  - LCD_SB_RIGHT;    // panel width in X
LCD_PANEL_SL   = LCD_PCB_SL - LCD_SB_FRONT - LCD_SB_BACK;     // panel depth along slope
LCD_PANEL_OX   = (LCD_SB_LEFT  - LCD_SB_RIGHT)  / 2;  // panel centre X shift from PCB centre
LCD_PANEL_OSL  = (LCD_SB_FRONT - LCD_SB_BACK)   / 2;  // panel centre slope shift from PCB centre

// ── LCD viewable area (window opening in cover) ───────────────
// Setbacks from the panel edges to the viewable/active area edges.
// The cover window is cut to this size (+ LCD_FIT_CLR per side).
// All zero until measured from the physical unit.
LCD_VIEW_SB_LEFT  = 9;   // panel -X edge → viewable area -X edge  — TBD
LCD_VIEW_SB_RIGHT = 2;   // panel +X edge → viewable area +X edge  — TBD
LCD_VIEW_SB_FRONT = 2;   // panel low-slope edge → viewable edge    — TBD
LCD_VIEW_SB_BACK  = 2;   // panel high-slope edge → viewable edge   — TBD

LCD_VIEW_X   = LCD_PANEL_X   - LCD_VIEW_SB_LEFT  - LCD_VIEW_SB_RIGHT;
LCD_VIEW_SL  = LCD_PANEL_SL  - LCD_VIEW_SB_FRONT - LCD_VIEW_SB_BACK;
LCD_VIEW_OX  = LCD_PANEL_OX  + (LCD_VIEW_SB_LEFT  - LCD_VIEW_SB_RIGHT)  / 2;
LCD_VIEW_OSL = LCD_PANEL_OSL + (LCD_VIEW_SB_FRONT - LCD_VIEW_SB_BACK)   / 2;

LCD_WIN_SKIN = 0.5;  // cover thickness over the LCD setback area (step shoulder depth from outer face)

REAR_CORNER_R = 3.0;  // rear top edge rounding radius (Y=OUTER_Y, Z=MAX_OUTER_Z corner)

// ── LCD PCB corner brackets ───────────────────────────────────
LCD_BRACKET_T   = 1.5;   // bracket wall thickness
LCD_BRACKET_W   = 5.0;   // bracket arm length along each PCB edge
LCD_BRACKET_GAP = 0.3;   // clearance between bracket inner wall face and PCB edge


// ── Fan (in MPI4008 kit sandwich) ────────────────────────────
FAN_SIZE = 30.0;   // fan square side — TBD
FAN_T    =  7.0;   // fan thickness  — TBD
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

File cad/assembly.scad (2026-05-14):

// ============================================================
// OctoMount — assembly.scad  (2-piece redesign, rev 6)
//
// Full assembly view: Base + Cover positioned together.
// OUTER_X = 145 mm (left wall at panel left edge; right wall at panel right edge).
//
// Flags:
//   SHOW_BASE      = 1  → render the base
//   SHOW_COVER     = 0  → render the cover (semi-transparent)
//   EXPLODE        = 0  → exploded view (cover lifted off base)
//   SHOW_RPI       = 1  → ghost RPi PCB inside
//   SHOW_LCD       = 1  → ghost LCD module (PCB + panel) inside
//   SHOW_BUCK      = 1  → ghost LM2596 buck converter (right of RPi)
//
// Ghost orientation: rotate([180+TILT_ANGLE,0,0]) from cover inner-face reference.
// RPi is mounted on BASE bosses; ghosts use BASE_OUTER_Z so they stay with
// the base in an exploded view (cover lifts independently via _cover_dz).
//   local +Z  → into cover interior (mostly world −Z)
//   local −Z  → outward through cover face (screen faces user / upward)
//   RPi PCB   → local Z: (STOFF_H−RPI_PCB_T) … STOFF_H
//              (bare-bottom at STOFF_H, rests on base bosses)
//   LCD PCB layer  → local Z: CLR_ABOVE_RPI+LCD_PANEL_T … CLR_ABOVE_RPI+LCD_T
//   LCD panel layer → local Z: CLR_ABOVE_RPI … CLR_ABOVE_RPI+LCD_PANEL_T
//                     (panel protrudes through cover window toward viewer)
// ============================================================
include <params.scad>
use <base.scad>
use <cover.scad>

SHOW_BASE       = 1;     // 1 = render base
SHOW_COVER      = 1;     // 1 = render cover

EXPLODE         = 0;
EXP_D           = 60;    // explode separation in mm

FLIP_OPEN       = 0;     // 1 = show cover flipped open around hinge axis (overrides EXPLODE)
FLIP_ANGLE      = 60;    // degrees open (90 = cover horizontal, 120 = leaning back)

SHOW_RPI        = 1;     // 1 = show ghost RPi PCB inside
SHOW_LCD        = 1;     // 1 = show ghost LCD module inside
SHOW_BUCK       = 1;     // 1 = show ghost LM2596 buck converter
SHOW_FAN40      = 1;     // 1 = show ghost 4010 fan (right-wall mounted)
SHOW_DEBUG      = 1;     // 1 = red spheres at boss-tip world positions

BASE_COL       = [0.3,  0.55, 0.75, 1.0];   // blue-grey, opaque
COVER_COL      = [0.25, 0.45, 0.65, 0.7];   // slightly darker, semi-transparent
RPI_COL        = [0.2,  0.7,  0.3,  0.85];  // green ghost
LCD_PCB_COL    = [0.9,  0.9,  0.3,  0.5];   // yellow ghost — PCB layer (behind)
LCD_PANEL_COL  = [0.95, 0.55, 0.1,  0.8];   // orange ghost — panel layer (front, in window)
BUCK_COL       = [0.7,  0.35, 0.1,  0.9];   // brown ghost — LM2596 buck converter
FAN40_COL      = [0.6,  0.6,  0.6,  0.7];   // grey ghost  — 4010 fan
SCREW_COL      = [0.75, 0.75, 0.8,  1.0];   // steel — M3 screws + nuts

// ── Shared M3 hardware dims ───────────────────────────────────
_m3_head_d  = 5.5;   // M3 pan-head diameter
_m3_head_h  = 2.0;   // M3 pan-head height
_m3_nut_r   = (5.5 / 2) / cos(30);  // M3 hex-nut circumscribed radius (AF=5.5mm)
_m3_nut_h   = 2.4;   // M3 hex-nut thickness

// ── Base at world origin ──────────────────────────────────────
if (SHOW_BASE)
    color(BASE_COL)
        base();

// ── Ghost: LM2596 buck converter (right of RPi, on base floor) ─
// Cube BUCK_X × BUCK_Y × BUCK_Z with four BUCK_HOLE_D clearance holes at boss positions.
// Right edge 2 mm from right wall inner face; PCB bottom at BASE_OUTER_Z + BUCK_FLOOR_H.
if (SHOW_BUCK)
    color(BUCK_COL)
        translate([OUTER_X - WALL - BUCK_WALL_GAP - BUCK_X,
                   WALL + BUCK_Y0,
                   BASE_OUTER_Z + BUCK_FLOOR_H])
            difference() {
                cube([BUCK_X, BUCK_Y, BUCK_Z]);
                for (bx = [(BUCK_X - BUCK_HOLE_X)/2, (BUCK_X + BUCK_HOLE_X)/2],
                     by = [(BUCK_Y - BUCK_HOLE_Y)/2, (BUCK_Y + BUCK_HOLE_Y)/2])
                    translate([bx, by, -0.05])
                        cylinder(d=BUCK_HOLE_D, h=BUCK_Z + 0.1, $fn=16);
            }

// ── Ghost: M3 screws for buck converter bosses ────────────────
// Four M3×10 pan-head screws through PCB mounting holes into base bosses.
// Heads shown above the full component height (BUCK_Z) so they're visible in the assembly.
// Shaft descends from head through PCB (1.6mm) into the boss (BUCK_FLOOR_H).
_buck_screw_l = BUCK_FLOOR_H + 1.6;  // shaft: through PCB + full boss depth

if (SHOW_BUCK)
    color(SCREW_COL)
        for (bx = [BUCK_FLOOR_X1, BUCK_FLOOR_X2],
             by = [BUCK_FLOOR_Y1, BUCK_FLOOR_Y2])
            translate([bx, by, BASE_OUTER_Z + BUCK_FLOOR_H + BUCK_Z]) {
                cylinder(d=_m3_head_d, h=_m3_head_h, $fn=16);           // head above module top
                translate([0, 0, -_buck_screw_l])
                    cylinder(d=3.0, h=_buck_screw_l, $fn=16);            // shaft down into boss
            }

// ── Ghost: 4010 fan (right-wall mounted, blowing inward −X) ──────────────
// Outer face at X = OUTER_X − WALL_S; body extends inward FAN40_T mm.
// Four M3 holes at ±FAN40_HOLE_P/2 in Y and Z from centre.
// STL bounding box: X=−20..20, Y=0..10, Z=−20..20 (centred in XZ, depth in Y).
// Face in XZ plane (normal = STL −Y).  rotate([0,0,90]) maps:
//   STL X → world Y (width), STL Y → world −X (depth inward), STL Z → world Z (height).
//   Face normal (STL −Y) → world +X (facing right wall from inside).
// Translate to fan-centre world pos so the centred-at-origin XZ extents land correctly.
if (SHOW_FAN40)
    color(FAN40_COL)
        translate([OUTER_X - WALL_S, FAN40_CY, FAN40_CZ])
            rotate([0, 0, 90])
                import("../reference/4010fanv1.stl", convexity=5);

// ── Ghost: M3 screws + hex nuts for fan mounting ──────────────
// Screws enter from outside right wall (+X side), nuts trapped on fan inner face.
// M3×16 pan-head: head protrudes outside wall, shaft through wall (2mm) + fan (10mm).
_m3_screw_l = 16.0;  // total screw length (head-face to tip)

if (SHOW_FAN40)
    color(SCREW_COL)
        for (dy = [-FAN40_HOLE_P/2, FAN40_HOLE_P/2],
             dz = [-FAN40_HOLE_P/2, FAN40_HOLE_P/2]) {
            // Screw: head on outer wall face, shaft going inward (−X)
            // rotate([0,90,0]) aligns local +Z with world +X
            translate([OUTER_X, FAN40_CY + dy, FAN40_CZ + dz])
                rotate([0, 90, 0]) {
                    cylinder(d=_m3_head_d, h=_m3_head_h, $fn=16);       // head outside
                    translate([0, 0, -_m3_screw_l])
                        cylinder(d=FAN40_HOLE_D, h=_m3_screw_l, $fn=16); // shaft inward
                }
            // Nut: on fan inner face (X = OUTER_X − WALL_S − FAN40_T)
            // rotate([0,-90,0]) aligns local +Z with world −X
            translate([OUTER_X - WALL_S - FAN40_T, FAN40_CY + dy, FAN40_CZ + dz])
                rotate([0, -90, 0])
                    cylinder(r=_m3_nut_r, h=_m3_nut_h, $fn=6);
        }

// ── Debug: red spheres at boss-tip world positions ────────────
// Uses the exact same transform chain as base.scad bosses → guaranteed correct.
if (SHOW_DEBUG)
    for (bx = BOSS_XS, by = BOSS_YS)
        color([1, 0, 0])
            translate([bx, by, BASE_OUTER_Z])
                rotate([TILT_ANGLE, 0, 0])
                    translate([0, 0, _BH_C + by * sin(TILT_ANGLE)])
                        sphere(r=2.0, $fn=16);

// ── Cover + internals ─────────────────────────────────────────
_cover_dz = BASE_OUTER_Z + EXPLODE * EXP_D;

if (SHOW_COVER)
    color(COVER_COL) {
        if (FLIP_OPEN)
            // Rotate cover around the hinge axis (X-parallel line at Y=BHINGE_Y, Z=BHINGE_WZ).
            // rotate([-FLIP_ANGLE,0,0]): front edge lifts upward (+Z), away from base.
            translate([0, BHINGE_Y, BHINGE_WZ])
                rotate([-FLIP_ANGLE, 0, 0])
                    translate([0, -BHINGE_Y, BASE_OUTER_Z - BHINGE_WZ])
                        cover();
        else
            translate([0, 0, _cover_dz])
                cover();
    }

// ── Ghost internals — RPi + LCD parallel to inner angled face ─
if (SHOW_RPI || SHOW_LCD) {
    _tan = tan(TILT_ANGLE);

    // RPi PCB centre in enclosure XY
    _rx_ctr = WALL + RPI_X0 + RPI_X/2;
    _ry_ctr = WALL + RPI_Y0 + RPI_Y/2;

    // LCD PCB centre = RPi centre + GPIO-coupled offset
    _lx_ctr = _rx_ctr + LCD_OFS_X;
    _ly_ctr = _ry_ctr + LCD_OFS_Y;

    // Pivot Z anchored to boss-tip plane so RPi bare-bottom sits flush on boss tops.
    // Boss tips lie at world Z = BASE_OUTER_Z + (_BH_C + by·sin θ)·cos θ.
    // Solving for the pivot that puts local Z = STOFF_H at that world Z:
    //   pivot_z = (_BH_C + STOFF_H)/cos θ + Y_centre·tan θ
    _boss_face_z = (_BH_C + STOFF_H) / cos(TILT_ANGLE);
    _rface_z = _boss_face_z + _ry_ctr * _tan;
    _lface_z = _boss_face_z + _ly_ctr * _tan;
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

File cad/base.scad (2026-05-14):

// ============================================================
// OctoMount — base.scad  (2-piece redesign, rev 6)
//
// OUTER_X = 145 mm (left wall at panel left edge; right wall at panel right edge).
// Right of RPi (X ≈ 96.8..142 mm) is the LM2596 buck converter zone (45 mm clear).
//
// The Base provides all enclosure walls plus the mounting bracket:
//   • Left + right side walls — tapered to match cover tilt angle
//   • Back wall + mounting plate — SAME WALL (fused, no arm-shelf gap)
//                                  Full enclosure height on enclosure span;
//                                  PLATE_H tall on PLATE_W mounting span.
//                                  M5 holes through back face into 4040 beam.
//   • Thin floor slab         — 4 mm
//   • Full-size SD slot       — notch in left wall
//   • USB-C entry slot        — notch in right wall (24V power input)
//   • M2.5 RPi mounting bosses  — 4 posts, tilted ⟂ to cover face, height varies with Y
//
// Side + back walls moved here from cover.scad (rev 6).
// The cover provides only the front wall + angled top slab.
//
// Wall heights from Z = 0:
//   Front edge:  COVER_FRONT_Z + BASE_OUTER_Z
//   Back edge:   MAX_OUTER_Z
//
// Print orientation: right-side up (back wall down, front face open).
// Material: PETG.
// ============================================================
include <params.scad>

base();

module base() {
    union() {
        difference() {
            _base_solid();
            _base_cuts();
        }
        // Front RPi bosses — tilted blind-hole boss with floor-flush base.
        // Hull of upright base disc + tilted cylinder fills the back-side gap
        // (where the tilted bottom circle lifts off the floor).
        // Intersection with z≥0 clips any front-side material below the floor bottom.
        // 4010 fan — flat wall pads around each M3 hole.
        // Added outside main difference() so vent cuts cannot reach them.
        // Disc spans exactly the wall thickness (WALL_S); no interior protrusion.
        for (dy = [-FAN40_HOLE_P/2, FAN40_HOLE_P/2],
             dz = [-FAN40_HOLE_P/2, FAN40_HOLE_P/2])
            difference() {
                translate([OUTER_X - WALL_S, FAN40_CY + dy, FAN40_CZ + dz])
                    rotate([0, 90, 0])
                        cylinder(r=M3_BOSS_R, h=WALL_S, $fn=32);
                translate([OUTER_X - WALL_S - 0.05, FAN40_CY + dy, FAN40_CZ + dz])
                    rotate([0, 90, 0])
                        cylinder(d=FAN40_HOLE_D, h=WALL_S + 0.1, $fn=16);
            }
        let(_h0 = max(0.5, _BH_C + BOSS_YS[0] * sin(TILT_ANGLE)))
        for (bx = BOSS_XS)
            difference() {
                intersection() {
                    hull() {
                        // Upright base disc — anchors boss to floor, fills back gap
                        translate([bx, BOSS_YS[0], 0])
                            cylinder(r=M25_BOSS_R, h=BASE_OUTER_Z, $fn=32);
                        // Tilted boss cylinder
                        translate([bx, BOSS_YS[0], BASE_OUTER_Z])
                            rotate([TILT_ANGLE, 0, 0])
                                cylinder(r=M25_BOSS_R, h=_h0, $fn=32);
                    }
                    // Clip: no material below z=0 (floor bottom)
                    translate([bx - M25_BOSS_R - 1, BOSS_YS[0] - M25_BOSS_R - 1, 0])
                        cube([2*(M25_BOSS_R+1), 2*(M25_BOSS_R+1), MAX_OUTER_Z]);
                }
                // Through hole: tip through tilted boss
                translate([bx, BOSS_YS[0], BASE_OUTER_Z])
                    rotate([TILT_ANGLE, 0, 0])
                        translate([0, 0, -0.1])
                            cylinder(d=M25_CLEAR, h=_h0 + 0.2, $fn=16);
                // Through-floor: vertical punch through the upright base cylinder
                translate([bx, BOSS_YS[0], -0.1])
                    cylinder(d=M25_CLEAR, h=BASE_OUTER_Z + 0.2, $fn=16);
            }
    }
}

// ── Solid geometry ────────────────────────────────────────────
module _base_solid() {
    // Floor slab — extended FRONT_EXT toward viewer (-Y)
    translate([0, -FRONT_EXT, 0])
        rbox([OUTER_X, OUTER_Y + FRONT_EXT, BASE_OUTER_Z]);

    // Left side wall — angled from front to _LCD_WIN_BACK_Y, then flat to back.
    // Three-point hull: slope = tan(TILT_ANGLE) up to the flat-top junction,
    // then constant MAX_OUTER_Z height to the back wall.
    hull() {
        translate([0, -FRONT_EXT, 0])
            cube([WALL_S, 0.01, COVER_FRONT_Z + BASE_OUTER_Z - FRONT_EXT * tan(TILT_ANGLE)]);
        translate([0, _LCD_WIN_BACK_Y - 0.01, 0])
            cube([WALL_S, 0.01, MAX_OUTER_Z]);
        translate([0, OUTER_Y - 0.01, 0])
            cube([WALL_S, 0.01, MAX_OUTER_Z]);
    }

    // Right side wall — mirror of left
    translate([OUTER_X - WALL_S, 0, 0])
    hull() {
        translate([0, -FRONT_EXT, 0])
            cube([WALL_S, 0.01, COVER_FRONT_Z + BASE_OUTER_Z - FRONT_EXT * tan(TILT_ANGLE)]);
        translate([0, _LCD_WIN_BACK_Y - 0.01, 0])
            cube([WALL_S, 0.01, MAX_OUTER_Z]);
        translate([0, OUTER_Y - 0.01, 0])
            cube([WALL_S, 0.01, MAX_OUTER_Z]);
    }

    // Back wall = mounting plate — single wall at Y = OUTER_Y − WALL_S .. OUTER_Y
    // Height = BKWALL_H: computed to leave clearance below the cover inner face when rotating.
    translate([0, OUTER_Y - WALL_S, 0])
        cube([OUTER_X, WALL_S, BKWALL_H]);

    // Extra 2 mm interior thickness on back wall: left side → left edge of bottom window.
    // Brings total thickness to WALL_S+2 in that region; the 2 mm counterbore for M5 heads sits here.
    translate([0, OUTER_Y - WALL_S - 2, 0])
        cube([BKWALL_WIN2_X0, 2, BKWALL_H]);

    // Front RPi bosses rendered in base() union.
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

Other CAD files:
cad/cover.scad
cad/legacy/p1_enclosure.scad
cad/legacy/p2_bracket.scad
cad/legacy/p3_bezel.scad
cad/legacy/p4_rear_panel.scad
cad/legacy/p5_buck_tray.scad
reference/6811d70143b4d50b11a59159.stl

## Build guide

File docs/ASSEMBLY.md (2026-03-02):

# Assembly Instructions

**Project:** OctoMount — RPi 4B + MPI4008 LCD enclosure for Ender 3 Pro
**Last Updated:** 2026-03-02
**Status:** Draft — pending CAD completion

> Diagrams and photos will be added to `/img` once the enclosure design is finalized.

---

## Enclosure Overview

```
  ┌─────────────────────────────────────────┐
  │           LCD BEZEL (front)             │
  │  ┌───────────────────────────────────┐  │
  │  │       MPI4008 4" Display          │  │
  │  │        (800 × 480, IPS)           │  │
  │  └───────────────────────────────────┘  │
  │                            [stylus slot]│
  └───────────────┬─────────────────────────┘
                  │  tilt bracket
  ┌───────────────┴─────────────────────────┐
  │           ENCLOSURE BODY                │
  │                                         │
  │  ┌──────────┐   fan (integrated)        │
  │  │ RPi 4B   │◄──────────────────────┐  │
  │  │  (PCB)   │                        │  │
  │  └──────────┘   ┌──────────────┐     │  │
  │                  │ Buck conv.   │     │  │
  │  [microSD slot]  │ LM2596+disp │     │  │
  │                  └──────────────┘     │  │
  │ LEFT SIDE:                            │  │
  │  [full-size SD slot]  [USB-A exit]    │  │
  │                                        │  │
  └───────────────┬────────────────[vents]─┘
                  │
  ┌───────────────┴──────┐
  │  2020 BRACKET        │  ← clamps to left front
  │  (tilted mount)      │    vertical extrusion
  └──────────────────────┘
```

---

## Part Identification

| Label | Part | Printed File |
|---|---|---|
| A | Main enclosure body | `P1_enclosure_body.stl` |
| B | 2020 extrusion bracket | `P2_bracket.stl` |
| C | LCD front bezel | `P3_lcd_bezel.stl` |
| D | Rear panel / lid | `P4_rear_panel.stl` |
| E | Buck converter tray | `P5_buck_tray.stl` |

---

## Tools Required

- Phillips / flathead screwdriver
- 2.5 mm hex key (M3 socket screws)
- 2 mm hex key (M2.5 screws)
- Wire strippers
- Crimping tool (for ferrules / spade terminals)
- Multimeter (to verify buck converter output voltage before connecting RPi)
- Soldering iron (optional, for USB-C pigtail)

---

## Step 1 — Print All Parts

1. Print parts P1–P5 in PETG.
2. Recommended settings:
   - Layer height: 0.2 mm
   - Infill: 30% (gyroid or grid)
   - Wall loops: 3
   - Supports: where required (primarily P2 bracket underside)
3. Post-process: remove supports, test-fit all parts dry before assembly.

---

## Step 2 — Prepare the Buck Converter

1. Slide the LM2596 module into tray **E** (P5).
2. Connect the 24V tap wires (red/black, 22 AWG) to the input terminals.
3. **Before connecting the RPi**, power on from the Ender 3 Pro PSU and use a multimeter to verify output is set to exactly **5.0–5.1V**. Adjust the trimmer pot as needed.
4. Power off before proceeding.

---

## Step 3 — Install the RPi 4B

1. Install M2.5 brass standoffs (×4) into the enclosure body floor (part **A**).
2. Set the RPi 4B onto the standoffs, USB ports facing the cable exit side.
3. Secure with M2.5 × 6 mm screws (×4).
4. Connect the USB-C pigtail (5V from buck converter) to the RPi USB-C power port.

---

## Step 4 — Mount the MPI4008 LCD

1. Align the MPI4008 GPIO header with the RPi 4B GPIO pins.
2. Press down firmly and evenly until fully seated — the integrated fan will sit in the gap between the two boards.
3. Confirm the micro HDMI cable (included with MPI4008 kit) is connected from the LCD board to the RPi micro HDMI port.

---

## Step 5 — Route the SD Extension Cable

1. Route the microSD end of the AliExpress extension cable (item 2255801037535913) through the internal channel in the enclosure body.
2. Insert the microSD plug into the Ender 3 Pro motherboard SD slot.
3. Seat the full-size SD female socket into the left-side panel cutout of the enclosure.
4. Ensure the cable has no sharp bends and is strain-relieved at both ends using the integrated cable clips in part **A**.

---

## Step 6 — Install Dust Filter

1. Cut dust filter mesh to match the ventilation opening(s) on the rear panel **D**.
2. Apply a thin bead of super glue or epoxy around the ventilation opening perimeter (inside face).
3. Press the mesh into place and hold until cured.
4. To clean: vacuum the exterior vent surface periodically.

---

## Step 7 — Install the LCD Bezel

1. Align the LCD bezel **C** over the front of the enclosure body **A**.
2. Confirm the display is fully visible through the bezel opening.
3. Secure bezel to enclosure with M3 × 8 mm screws.
4. Insert stylus into the clip slot on the side of the bezel.

---

## Step 8 — Close the Rear Panel

1. Route all internal wiring clear of the rear panel seating surface.
2. Press rear panel **D** (with dust filter installed) onto the enclosure body.
3. Secure with M3 × 8 mm screws.

---

## Step 9 — Mount to Ender 3 Pro Frame

1. Slide M3 T-slot nuts into the 2020 left front vertical extrusion.
2. Position the bracket **B** at the desired height (~elbow height when standing).
3. Align the enclosure tilt angle toward the operator.
4. Tighten M3 × 12 mm screws through the bracket into the T-slot nuts.
5. Verify the assembly does not protrude into the printer bed Y-axis travel path or obstruct X-axis gantry wheels.

---

## Step 10 — Connect USB to Printer

1. Plug the USB-A end of the USB cable into the RPi 4B USB-A port.
2. Route the cable through the enclosure exit opening.
3. Plug the micro-USB end into the Ender 3 Pro front USB port.

---

## Step 11 — Power On & Verify

1. Power on the Ender 3 Pro.
2. Confirm the buck converter LED voltmeter reads 5.0–5.1V.
3. Confirm the RPi 4B boots and the MPI4008 LCD displays the OctoPi interface.
4. Confirm touch input works on the LCD.
5. Test SD card insertion/removal from the full-size slot on the left side.

---

## Wiring Diagram

> To be added — see `/img/wiring_diagram.png` (pending)

---

## Troubleshooting

| Symptom | Likely Cause | Fix |
|---|---|---|
| RPi doesn't boot | Buck converter output not at 5V | Re-check and adjust trimmer pot |
| LCD no display | Micro HDMI not seated / driver not installed | Reseat cable; install MPI4008 driver |
| Touch not working | GPIO header not fully seated | Remove and re-seat LCD module |
| SD slot not reading | Extension cable bent or damaged | Inspect cable routing |
| Overheating | Fan not running / vents blocked | Check fan wiring; clear obstructions |

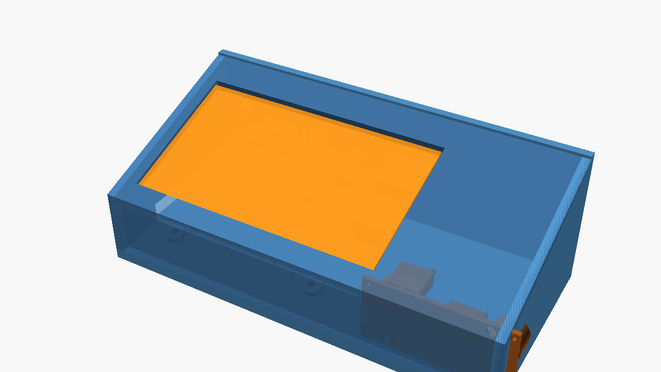
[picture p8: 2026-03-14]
preview_assembly.png

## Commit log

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2026-03-05 Redesign docs: pivot to 2-piece Base+Cover design
    - REQUIREMENTS.md: rewrite for 2-piece design, M5 4040 beam mounting,
    45° LCD tilt, USB-A back wall, USB-C right-bottom corner, buck inside
    base with adhesive heatsink; remove stylus/bezel/rear panel/tray reqs
    - PARTS.md: update BOM to 2 printed parts, correct fasteners (M5×12
    flat-head, M2.5×8, M3×8 cover screws), add LM2596 adhesive heatsink
    and USB-A extension; remove T-slot nuts and old bracket screws
    - STATUS.md: document design pivot, update Phase 2 tasks for redesign,
    add open issues for pending measurements
    - README.md: update overview, mounting strategy, port table, parts list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
2026-03-05 Add 48mm max height constraint (bed clearance)
    - REQUIREMENTS.md: add REQ-002.12 (OUTER_Z ≤ 48mm hard limit) and
    REQ-002.13 (RPi must be mounted flat, not on-edge, to meet limit)
    - cad/params.scad: add MAX_OUTER_Z = 48.0 with assert that will catch
    any future params.scad update that violates the limit; note that the
    current 5-piece layout (OUTER_Z = 81mm) is superseded
    [params.scad]
2026-03-05 Maximise LCD tilt instead of fixing at 45°
    Back wall at the 48mm height limit, front wall at minimum height above
    the flat RPi stack. Angle is derived from geometry, not prescribed.
    Side silhouette changes from 45°-corner-cut rectangle to right-trapezoid.
    Remove all hardcoded 45° references from REQUIREMENTS, README, STATUS.
2026-03-05 Refresh preview; downgrade height assert to echo warning
    assert() was blocking render of the transitional 5-piece CAD.
    Changed to echo() with TODO to restore as assert when 2-piece
    params replace the current layout.
    [params.scad]
2026-03-05 2-piece CAD redesign: base.scad + cover.scad + params.scad
    params.scad — rewritten for flat RPi orientation (56mm X, 85mm Y,
    ~22mm Z); derived BASE_OUTER_Z=32mm, COVER_BACK_Z=16mm giving ~8°
    LCD tilt from horizontal (maximised within 48mm height limit);
    buck fits beside RPi in X zone; echo tilt angle on render
    base.scad — new: open-top tray + mounting plate + arm shelf;
    RPi standoff bosses (4× M2.5); M3 cover-attachment bosses (4 corners);
    USB-A + Ethernet openings in back wall; USB-C slot right-bottom corner;
    full-size SD slot left wall; M5 countersunk holes in mounting plate
    cover.scad — new: hull()-based right-trapezoid shell (front lip 3mm,
    back wall 16mm); LCD ac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
    [assembly.scad, base.scad, cover.scad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]
2026-03-05 Housekeeping: gitignore, legacy archive, STATUS update, reference files
    - .gitignore: add .claude/ exclusion
    - cad/legacy/: archive superseded 5-piece scad files (p1–p5)
    - STATUS.md: mark 2-piece CAD tasks complete (params/base/cover/assembly)
    - cad/README.md: add CAD directory readme
    - reference/: add hardware reference drawings (4040 profile, RPi dims)
    [p1_enclosure.scad, p2_bracket.scad, p3_bezel.scad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]
2026-03-06 Redesign cover: 39° LCD tilt, snug PCB recess
    Replace the MAX_OUTER_Z-derived cover geometry with a fixed TILT_ANGLE=39°.
    Cover back wall is now ~78 mm (derived from OUTER_Y × tan(39°)); total
    enclosure height at the back corner is ~110 mm.
    LCD PCB recess tightened to LCD_FIT_CLR=0.5 mm per side (was CLR=1.0 mm)
    so the screen seats flush and snug into the angled cover face.
    [cover.scad, params.scad]
2026-03-06 Maximise tilt within 52 mm: shorter base, narrower plate, derived angle
    - STOFF_H 5→3 mm, CLR_ABOVE_RPI 2→1 mm → BASE_OUTER_Z 32→29 mm
    - MAX_OUTER_Z = 52 mm (narrower 125 mm plate, left-aligned, right side
    clear for bed-mount screws)
    - TILT_ANGLE derived from geometry: atan(20/93) ≈ 12.1° (was fixed 39°)
    - Add PLATE_X0 as fixed left-edge reference so plate width and alignment
    are independent parameters
    - Note: add floor/wall grooves if cable routing is tight under RPi
    [base.scad, params.scad]
2026-03-06 Fix M25_BOSS_DEPTH bug; update stale comments
    - M25_BOSS_DEPTH 5→3 mm: must not exceed STOFF_H (3 mm) or the
    tapped hole extends below the boss base into the floor
    - params.scad header: height ceiling updated to 52 mm
    - base.scad: plate described as left-aligned (not centred)
    - cover.scad: COVER_BACK_Z derivation comment corrected
    [base.scad, cover.scad, params.scad]
2026-03-06 Tilt RPi+LCD assembly inside cover; base becomes 10 mm wiring slab
    - params.scad: STOFF_H = ASSEMBLY_DEPTH = CLR+LCD_T+RPI_T = 28 mm
    (full standoff from cover inner face to RPi PCB bottom)
    BASE_OUTER_Z fixed at 10 mm; COVER_FRONT_Z = WALL + ASSEMBLY_DEPTH = 31 mm;
    COVER_BACK_Z = 42 mm; TILT_ANGLE ≈ 6.7°; remove BASE_INNER_Z
    - base.scad: remove RPi standoff bosses, USB-A/ETH openings, M2.5 holes;
    keep SD slot, USB-C power entry, M3 bosses, arm shelf, plate
    - cover.scad: restructure cover() as diff(union(diff(shell,void)+bosses), cuts);
    add _cover_rpi_bosses() — 28 mm bosses perpendicular to inner angled face
    via rotate([180+TILT_ANGLE, 0, 0]); remove snug PCB recess (TBD afte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
    [base.scad, cover.scad, params.scad]
2026-03-06 assembly.scad: add ghost RPi + LCD internals preview
    SHOW_INTERNALS = 1 renders semi-transparent green RPi block and
    yellow LCD block inside the cover, aligned to the inner angled face.
    EXPLODE = 1 still separates base and cover for inspection.
    [assembly.scad]
2026-03-06 Fix ghost RPi block: was 22 mm too deep (double-counted RPI_T); fix Y-centre Z ref
    - RPi cube: translate z = -STOFF_H (not -(STOFF_H+RPI_T))
    - Both blocks: inner face Z evaluated at block Y-centre, not front edge
    [assembly.scad]
2026-03-06 Express LCD position as fixed relative to RPi (GPIO-coupled unit)
    - params.scad: add LCD_OFS_X/Y (LCD PCB centre offset from RPi centre,
    measured from coupled assembly; both 0.0 TBD)
    - assembly.scad: derive LCD ghost centre from RPi centre + LCD_OFS_X/Y
    instead of independently using OUTER_X/2
    [assembly.scad, params.scad]
2026-03-12 Fix boss alignment, height formula, and enclosure depth
    - params.scad: correct _BH_C formula (was STOFF_H·cos²θ, should be STOFF_H)
    → bosses were protruding ~1.3 mm through RPi PCB
    - params.scad: fix BOSS_YS — tilted boss tip shifts −Y by h·sin θ; base
    position now solved as (hole_world_y + _BH_C·sin θ) / cos²θ
    - params.scad: rpi_boss module clamps tapped-hole depth to min(h, M25_BOSS_DEPTH)
    so short front bosses (~2.8 mm) don't punch through the base floor
    - params.scad: increase INNER_Y 60.1 → 65.0 mm; tilted RPi bare-bottom edge
    reaches world_y ≈ 65.2 mm (θ≈19°), previously intersecting the back wall
    - assembly.scad: replace SHOW_INTERNALS with separate SHOW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
    [assembly.scad, base.scad, cover.scad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]
2026-03-14 Widen enclosure to 125.8 mm; add buck converter ghost; update assembly view
    params.scad:
    - INNER_X widened from 100.6 mm to 119.8 mm (right wall now at right edge
    of 145 mm back panel: OUTER_X = 125.8 mm)
    - PLATE_X0 and RPI_X0 refactored to fixed constants independent of OUTER_X,
    keeping all internal features at the same position relative to left wall
    - BUCK dims updated to LM2596 actuals: 21 × 43 × 17 mm
    cover.scad:
    - Fix LCD window centre: OUTER_X/2 (62.9 mm) → WALL+RPI_X0+RPI_X/2 (53.3 mm)
    assembly.scad (rev 6):
    - SHOW_COVER = 1 (was 0); SHOW_DEBUG = 0; add SHOW_BUCK + buck ghost
    - Buck ghost positioned at WALL+BUCK_X0, WALL+BUCK_Y0 (right of RPi)
    base.scad (rev 6):
    - Header no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
    [6811d70143b4d50b11a59159.step, 6811d70143b4d50b11a59159.stl, Raspberry_Pi_4_B_3D_Model.stl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]
2026-03-14 assembly: replace buck cube ghost with actual LM2596 STL model
    Rotate 90° around Z so the short axis (15.8 mm) occupies the 27 mm
    X slot right of the RPi; the long axis (50.9 mm) runs front-to-back.
    Translate to seat the model on the base floor at WALL+BUCK_X0/Y0.
    [assembly.scad]
2026-03-14 Widen enclosure to 145 mm; lay buck flat; align left wall with panel
    - PLATE_X0 = 0 (left wall now aligns with panel left edge — no bracket overhang)
    - INNER_X = 145 − 2×WALL = 139 mm; OUTER_X = 145 mm (full panel width)
    - RPI_X0 = 7.8 mm (unchanged relative to left wall)
    - Buck zone right of RPi: 139 − 92.8 = 46.2 mm clear
    - Cable slot X positions updated: USB 18.5..34.5 mm, SD 38.3..47.3 mm
    base.scad: update header and cable-slot comments for new geometry
    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
    [assembly.scad, base.scad, params.scad]
2026-03-14 Buck converter: flat on floor, long axis along Y, M3 boss posts
    - assembly.scad: rotate([0,0,90]) so 50.9mm long axis runs in enclosure
    Y (along right side wall); PCB sits on 3mm bosses above base floor
    - base.scad: add two M3 boss posts at mounting hole positions
    (BUCK_BOSS_X≈111.6mm, Y1≈10.4mm, Y2≈42.4mm)
    - params.scad: add BUCK_BOSS_H/X/Y1/Y2 derived from STL hole analysis
    [assembly.scad, base.scad, params.scad]
2026-03-15 Buck: 90° CW around long edge → flat on floor, component side to right wall
    - assembly.scad: rotate([0,90,0])∘rotate([0,0,90]); STL(x,y,z)→(z,x,y); module
    height drops from 24.3 mm to 15.8 mm (PCB short width); component tops at right wall
    - params.scad: replace floor bosses with horizontal wall-boss params
    (BUCK_BOSS_Z≈5mm, BUCK_BOSS_L=23.5mm, Y1≈10.4mm, Y2≈42.4mm)
    - base.scad: replace vertical floor bosses with horizontal posts from right side wall
    (rotate([0,-90,0]) m3_boss); screw from interior through PCB hole into boss tapped end
    [assembly.scad, base.scad, params.scad]
2026-03-16 Buck: 2mm wall gap + floor bosses at confirmed PCB hole positions
    - Move buck 2mm from right wall (BUCK_WALL_GAP=2.0)
    - Replace horizontal wall bosses with 2x vertical M3 floor bosses
    (BUCK_FLOOR_H=4mm, PCB rests at BASE_OUTER_Z+4)
    - Floor boss XY from STL Y-axis hole analysis:
    front: STL(x=-0.2, z=28.1) -> world(117.6, 6.2)
    back: STL(x=46.2, z=28.1) -> world(117.6, 52.6)
    - assembly.scad ghost raised 4mm to match boss height
    [assembly.scad, base.scad, params.scad]
2026-03-16 Buck: expand to 4 floor bosses (full corner pattern)
    Add second X position for the component-side PCB edge holes.
    All 4 corners confirmed from STL Y-axis hole analysis:
    front pair: STL z=28.0 and z=48.7 (x≈0) → world_x 117.5 and 138.2
    back pair: STL z=28.0 and z=48.7 (x≈46.4) → world_x 117.5 and 138.2
    base.scad uses for(bx=[X1,X2], by=[Y1,Y2]) 2x2 loop.
    [assembly.scad, base.scad, params.scad]
2026-03-16 Back wall: single cable window, positions corrected to right-wall reference
    - Two separate USB-A + SD slots replaced by one combined window
    - Positions were wrongly measured from the left; corrected to measure
    from the right wall (OUTER_X) matching the Ender 3 panel drawing
    - Window: X = OUTER_X-47.3 .. OUTER_X-18.5 (97.7..126.5 mm), Z = 21..30 mm
    - Covers both USB-A (18.5..34.5 from right) and SD (38.3..47.3 from right)
    [base.scad, params.scad]
2026-03-16 Back wall window: fix 8mm position error, anchor to M5 holes
    Previous commit used OUTER_X=145 as right reference; panel diagram
    measures from full panel right edge (153mm) — 8mm difference.
    Window now anchored to M5 screws as base reference:
    X: MOUNT_H2[0] + 75.7 .. MOUNT_H2[0] + 104.5 (= 105.7..134.5 mm)
    Z: MOUNT_H1[1]-9 .. MOUNT_H1[1] (= 21..30 mm)
    M5 hole spacing verified against Ender3PanelDiagram.pdf:
    MOUNT_H1=[10,30] at 143mm from panel right ✓
    MOUNT_H2=[30,10] at 123mm from panel right ✓
    ΔX=20mm, ΔZ=20mm, diagonal=28.3mm ✓
    [params.scad]
2026-03-16 Back wall window: fix Z position — anchor to PLATE_H not MOUNT_H1
    Panel diagram right-side labels (0, 6, 9, 10, 30) are DEPTH FROM TOP
    EDGE, not absolute Z. Z = PLATE_H − depth gives:
    MOUNT_H1 at depth 10 → Z 30 ✓ MOUNT_H2 at depth 30 → Z 10 ✓
    Ports at depth 0..9 → Z 31..40 (just above top M5 screw hole)
    Previous window Z=21..30 was 10 mm too low (had used MOUNT_H1[1]=30 as
    ZHI instead of PLATE_H=40). New: BKWALL_WIN_ZHI=PLATE_H=40,
    BKWALL_WIN_ZLO=PLATE_H−9=31.
    [params.scad]
2026-03-16 SD slot: correct dimensions + two M2 floor screw holes
    - SD_W 32→40.4 mm, SD_H 8→4 mm (measured from physical SD holder)
    - Slot bottom remains at BASE_OUTER_Z (flush with inside floor)
    - Add SD_SCREW_D/SPAN/X params; cut two 2 mm Ø holes through floor slab
    at Y = OUTER_Y/2 ± 34.1/2 (evenly flanking slot centre),
    X = 7.8 mm from outside left wall surface
    [base.scad, params.scad]
2026-03-16 SD floor screws: correct X from 7.8 → 17.8 mm from left wall
    [params.scad]
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2026-03-16 SD slot: move toward back wall, back screw 8 mm from inner back wall
    Replace fixed OUTER_Y/2 centre with derived SD_CY:
    SD_CY = OUTER_Y − WALL − SD_BACK_CLR − SD_SCREW_SPAN/2
    back screw at OUTER_Y − WALL − 8 = inner back wall − 8 mm
    SD_CY defined after OUTER_Y to avoid forward-reference warning.
    [base.scad, params.scad]
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2026-03-16 Cover: fit between side walls, ball hinges on inner side-wall faces
    - Cover (rev 7) narrows to INNER_X (fits between side walls, not over them);
    front wall and angled top slab offset by WALL in X
    - Ball hinges: exact half-spheres at cover side faces (X=WALL / X=OUTER_X-WALL);
    matching hemisphere sockets on inner faces of base side walls
    - BKWALL_H reduced by extra 3 mm so sockets sit fully inside side-wall material
    - BHINGE_WZ lowered to 48.5 mm giving ~1.5 mm margin below side-wall top
    - Cover back-top edge (between hinges) filleted with 2 mm cylinder so cover
    sweeps clear of walls when flipped open
    [base.scad, cover.scad, params.scad]
2026-03-16 Cover: LCD left-edge alignment, hinge ridge, rotation-clearance fillets
    - params.scad: LCD_OFS_X = (LCD_PCB_X − RPI_X)/2 = 6.8 mm so LCD PCB
    left edge aligns with RPi PCB left edge; remove BHINGE_EDGE_R
    - cover.scad: replace back-top subtracted fillet with additive cylinder
    ridge (r=BHINGE_R, spans INNER_X) connecting the two half-balls —
    smooth convex hinge surface for rotation
    - cover.scad: add two rotation-clearance cylinder subtractions:
    (1) front inner-bottom slab edge (catches during first opening arc)
    (2) outer-top-back corner at (Y=OUTER_Y, Z=COVER_BACK_Z)
    (clips base back wall when cover opens past ~120°)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
    [cover.scad, params.scad]
2026-03-16 Cover: convex (outward) round on outer-top-back edge
    Replace the concave cylinder subtraction at the back-top corner with a
    convex round: add _cover_back_round() (cylinder r=CORNER_R, centre inset
    CORNER_R from both faces, tangent to top and back faces) to the union,
    and subtract the square corner block from _cover_cuts(). The result is
    an outward-bulging curve that sweeps cleanly past the base back wall
    when the cover opens past 120°.
    [cover.scad]
2026-03-16 Cover: back face → circular arc centred on hinge axis
    Replace the flat back face + CORNER_R convex round with a true circular
    arc whose centre is the hinge axis and radius = distance(hinge →
    back-top corner) ≈ 3.8 mm.
    Construction: intersection of (outer cylinder, r=_ro, centred on hinge)
    ∩ (Y ≥ BHINGE_Y half-space) ∩ (extended slab bounding volume).
    The extended slab clips the arc to the angled face planes so it is
    seamlessly flush with the rest of the cover.
    When the cover rotates it sweeps exactly this cylinder, so the back
    face can never clip the base back wall at any opening angle.
    [cover.scad]
2026-03-17 Cover: fix arc back-face — slab trimmed inside its own module
    The rectangular cut in cover() was also removing the arc, leaving the
    slab truncated and the arc floating as a separate piece.
    Fix: clip the slab to Y < BHINGE_Y via _cover_top_slab_trimmed()
    (intersection inside the module) so _cover_back_arc() owns the back
    section exclusively. No top-level back-section cut needed.
    [cover.scad]
2026-03-17 Cover: simplify back arc — protrusion beyond slab only, no slab trimming
    Previous approach clipped the arc with an extended slab hull which
    over-extended the cylinder far above the slab outer face, creating a
    large visible dome.
    New approach:
    - Revert to full _cover_top_slab() (no trimming at BHINGE_Y)
    - _cover_back_arc() now adds ONLY the material past Y=OUTER_Y,
    clipped to the slab Z thickness at the back (COVER_BACK_Z-_wz..COVER_BACK_Z)
    - The slab's flat back face (Y=OUTER_Y) is unchanged; the arc cap
    protrudes ~2 mm further, tangent to both the outer and inner slab faces
    - Remove _cover_top_slab_trimmed() and _cover_top_slab_ext()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
    [cover.scad]
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2026-03-17 Cover: fix LCD window pocket direction — keep outer (top) skin
    _lZ is on the outer face, so local +Z = inward into the slab.
    Pocket now starts at +LCD_WIN_SKIN (1 mm inward from top face),
    keeping the outer/top surface intact.
    Previous code started at -(_wz-skin) which kept the inner/bottom skin instead.
    [cover.scad]
2026-03-17 LCD window: blind pocket from inner face, 1 mm outer skin retained
    Pocket starts 1 mm past the inner slab face (−_win_d) and stops
    LCD_WIN_SKIN (1 mm) short of the outer face, keeping the top surface
    intact. Local +Z = outward in the rotated frame, so the start must be
    negative (inward); previous attempt used +LCD_WIN_SKIN which placed the
    pocket origin above the outer face in empty air.
    [cover.scad]
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2026-03-17 LCD window: outer (viewable) cut starts from -_deep, not -_step
    The step shoulder is created by the inner (panel-sized) cut ending at
    -_step, leaving solid material in the panel annular region from -_step
    to the outer face. The outer (viewable-area) cut therefore does not
    need to start at -_step — starting it from -_deep (same origin as the
    inner cut) guarantees it clears the full slab thickness and the outer
    face is completely open with no risk of a missed-face artefact.
    [cover.scad]
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2026-03-17 cover: remove rotation-clearance fillet from front inner edge
    [cover.scad]
2026-03-17 cover: add two stylus snap-clips on outer slab face
    Each clip is a C-ring (axis along world X = stylus direction) sitting on
    the outer slab face between the front edge and the LCD window. Opening
    faces outward (+Z) with an 85%-diameter snap gap for PETG flex fit.
    Clips are added outside the main difference() so the yellow cut does
    not trim them.
    New params: STYLUS_D, STYLUS_CLR, STYLUS_CLIP_T, STYLUS_CLIP_W,
    STYLUS_CLIP_Y, STYLUS_CLIP_DX
    [cover.scad, params.scad]
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2026-03-17 LCD brackets: move right posts into tilted local frame for exact alignment
    World-space formula produced misaligned posts due to the tilt. Posts are
    now cubes in the same rotate([180+TILT,0,0]) frame as the brackets, from
    local Z=CLR_ABOVE_RPI+LCD_T down to the base floor (z_floor = (lfz - y*sinT)/cosT),
    guaranteeing flush connection with the bracket floor ledge.
    [base.scad]
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2026-03-17 LCD brackets: replace left bridges with extended floor ledge to left wall
    Remove two separate bridge beams. Extend the left floor rail from
    X = WALL-_lx (left wall inner face) to X = -LCD_PCB_X/2 (PCB left edge),
    creating one continuous shelf connecting the bracket to the wall.
    [base.scad]
2026-03-17 LCD brackets: left shelf — two strips aligned with bracket front/back walls
    Replace full-Y slab with two _t-thick strips at Y=±LCD_PCB_SL/2,
    matching the outer face of the bracket X-walls at each end.
    [base.scad]
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2026-03-17 LCD brackets: add two ribs to left extension plate
    Two _t-thick fins along X at Y = ±LCD_PCB_SL/6, standing from
    CLR_ABOVE_RPI+LCD_PANEL_T to CLR_ABOVE_RPI+LCD_T (same height as
    bracket walls), stiffening the extension plate.
    [base.scad]
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2026-03-17 LCD brackets: double right post thickness to 4t×4t, outer faces fixed
    Right X face stays flush with rail outer edge; outer Y face of each
    post stays at its current position; posts grow inward/toward center.
    [base.scad]
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2026-03-18 Buck converter ghost: replace STL with parametric cube + screw holes
    [assembly.scad]
2026-03-18 LCD brackets: reroute right-side support clear of buck converter
    - Remove back right post (conflicts with buck converter X zone)
    - Add back-wall bridge above cable window (Z ≥ BKWALL_WIN_ZHI) to replace it
    - Move front right post left: right edge = buck left − CLR, left edge clears RPi
    - Add front-right floor ledge extension in local tilted frame to connect bracket firmly to moved post
    [base.scad]
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2026-03-18 Buck converter: move to back wall (4 mm clearance, BUCK_Y0 1→5 mm)
    [params.scad]
2026-03-18 Fix buck standoffs not rendering: replace OUTER_X with INNER_X+WALL
    OUTER_X was referenced in BUCK_FLOOR_X2 at global scope before it was
    defined (line 182 vs 189). OpenSCAD evaluates globals top-to-bottom, so
    OUTER_X was undef → standoffs translated to (undef,Y,Z) → silently dropped.
    INNER_X+WALL is identical in value and is defined at line 152.
    [params.scad]
2026-03-18 LCD brackets: add 0.3 mm clearance gap from PCB edges
    New param LCD_BRACKET_GAP = 0.3 mm. Applied in _lcd_corner_bracket():
    walls shifted outward by gap, floor ledge extended to match.
    No changes to bracket placement or other support geometry.
    [base.scad, params.scad]
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2026-03-18 Back-boss plate: extend to fully reach back wall
    Previous _D formula left the plate short of OUTER_Y - WALL due to the
    tilt-induced Z offset (_hb - _ts) not being compensated. New formula:
    _D = (OUTER_Y - _by + (_hb - _ts)*sin(T)) / cos(T) + M25_BOSS_R
    makes the plate's far tilted face land at world Y = OUTER_Y, fully
    penetrating and fusing with the back wall.
    [base.scad]
2026-03-18 Back RPi bosses: replace rpi_back_block with holes in connecting plate
    The individual back-boss slabs were buried inside the connecting plate,
    making them invisible/redundant. Replace with the plate alone and add
    two M2.5 blind tap holes directly in the plate at the former boss-tip
    world positions (same tilted frame, depth = M25_BOSS_DEPTH from top face).
    [base.scad]
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2026-04-17 Cover/base: rear edge rounding, back-boss split ribs, back-wall tab + M5 counterbores
    - cover + base: round rear-top edge (r=3 mm) via quadrant_cube − quadrant_cylinder
    - base: split full-width RPi back-boss plate into two narrow tilted pads with
    triangular support ribs; Rib 4 narrowed to WALL_S at right boss outer edge
    - base: add 2 mm interior tab on back wall (X=0..BKWALL_WIN2_X0) with M5
    counterbores (d=9.5 mm, 2 mm deep) for mounting screw head clearance
    - params: add REAR_CORNER_R = 3.0
    [assembly.scad, base.scad, cover.scad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]
2026-04-18 Cover: stylus groove + finger relief; back wall unified; vent grill extended; flip-open view
    - cover: half-cylinder stylus groove sinking into flat top (D=8mm, L=100mm)
    - cover: ergonomic ellipsoid finger relief at groove midpoint (same depth as groove)
    - cover: groove cut moved to outermost difference so it cuts through angled slab material
    - cover: assembly FLIP_OPEN/FLIP_ANGLE params to show cover hinged open around actual hinge axis
    - base: back wall unified to single cube([OUTER_X, WALL_S, BKWALL_H]) — no more two-piece step
    - base: vent grill extended — extra row of 6 at Z=33.5mm, new front column at Y=-3mm, rear column of 6 at Y=69mm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
    [assembly.scad, base.scad, cover.scad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]
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2026-05-14 Cover: fan nut clearance cut; RPi/buck position updates; 4010 fan params
    - cover: add _fan40_clearance_cut() with STL-hull body cut + 9 mm interior
    rectangular extension (FAN40_NUT_CLR) for M3 nut clearance away from right wall
    - params: add FAN40_* parameters; shift RPI_X_SHIFT to -8.5 (left-wall flush);
    BUCK_WALL_GAP 1→10.5 mm, BUCK_FLOOR_H 4→8 mm
    - remove reference/Sheetmetal enclosure bottom.pdf (superseded)
    [assembly.scad, base.scad, cover.scad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]
